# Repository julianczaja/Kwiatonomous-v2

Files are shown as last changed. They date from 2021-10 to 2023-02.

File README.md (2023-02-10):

# Kwiatonomous-v2 

##### Kwiatonomous is a device for automatic plant watering. ESP8266 based, battery powered (super low power), own backend (in Ktor) and Android app (with Jetpack Compose).

___

### Android App
<p align="center">
  
</p>

___

### Hardware
#### v0.5 (306070 Li-Po)
<p align="middle">
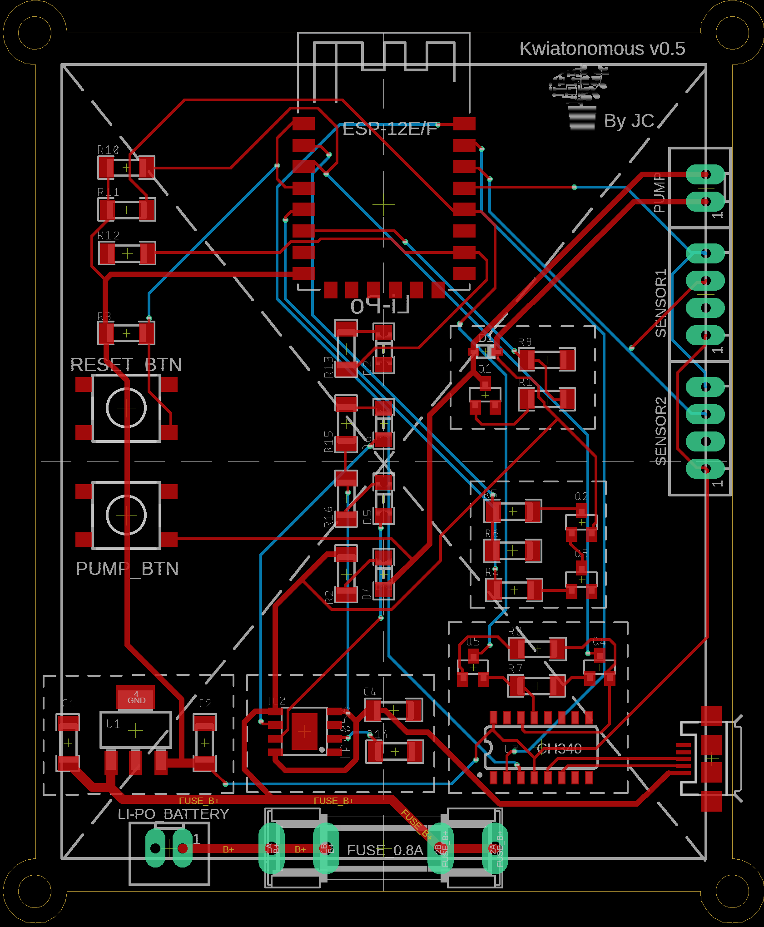
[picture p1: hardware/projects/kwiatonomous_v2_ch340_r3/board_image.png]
  
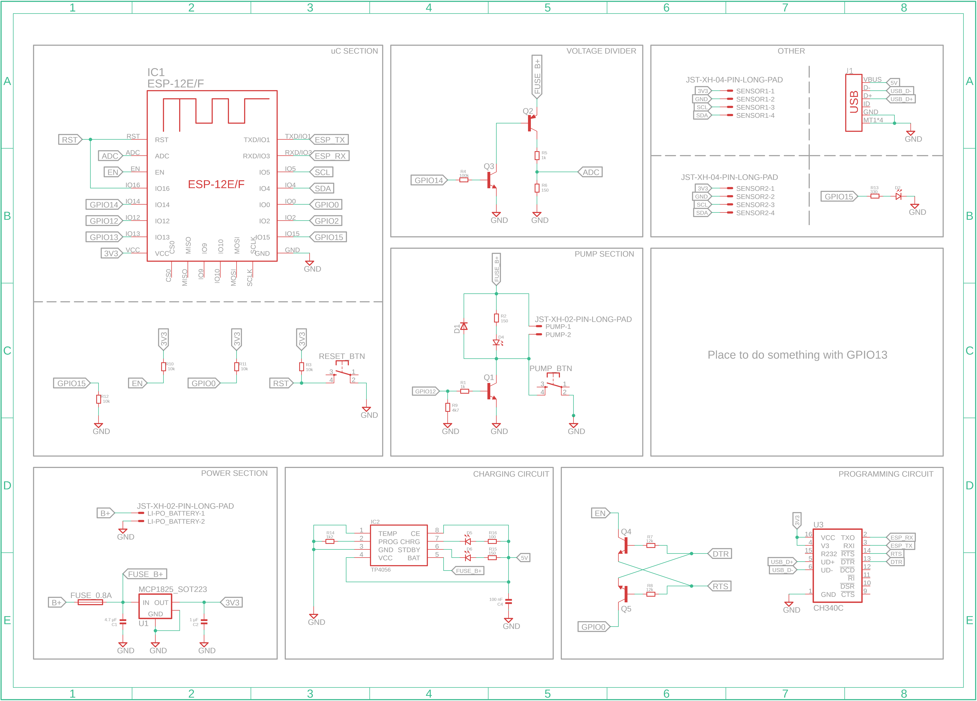
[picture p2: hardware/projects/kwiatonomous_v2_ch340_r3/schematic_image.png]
  
</p>

<details>
  <summary>v0.4 (Li-ion 18650)</summary>
  <p align="middle">
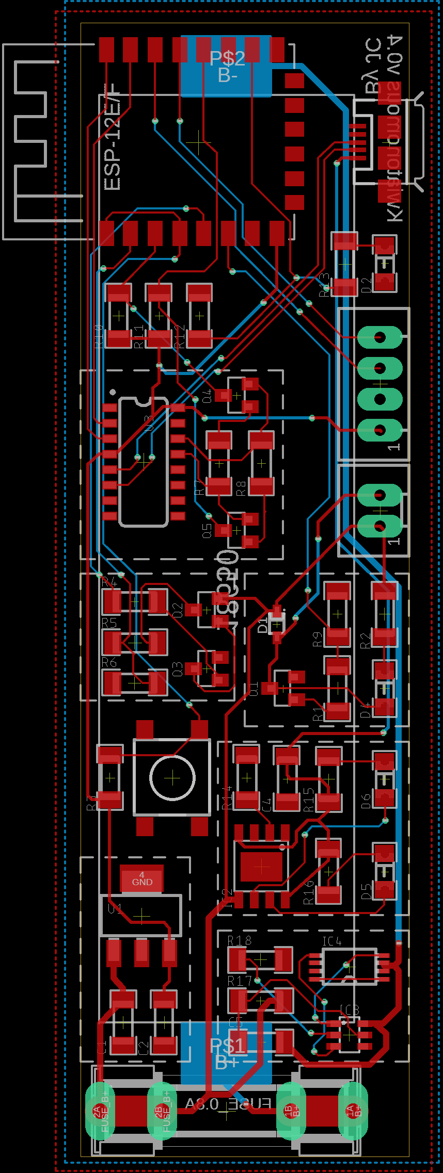
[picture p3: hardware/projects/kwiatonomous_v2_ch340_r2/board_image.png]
    
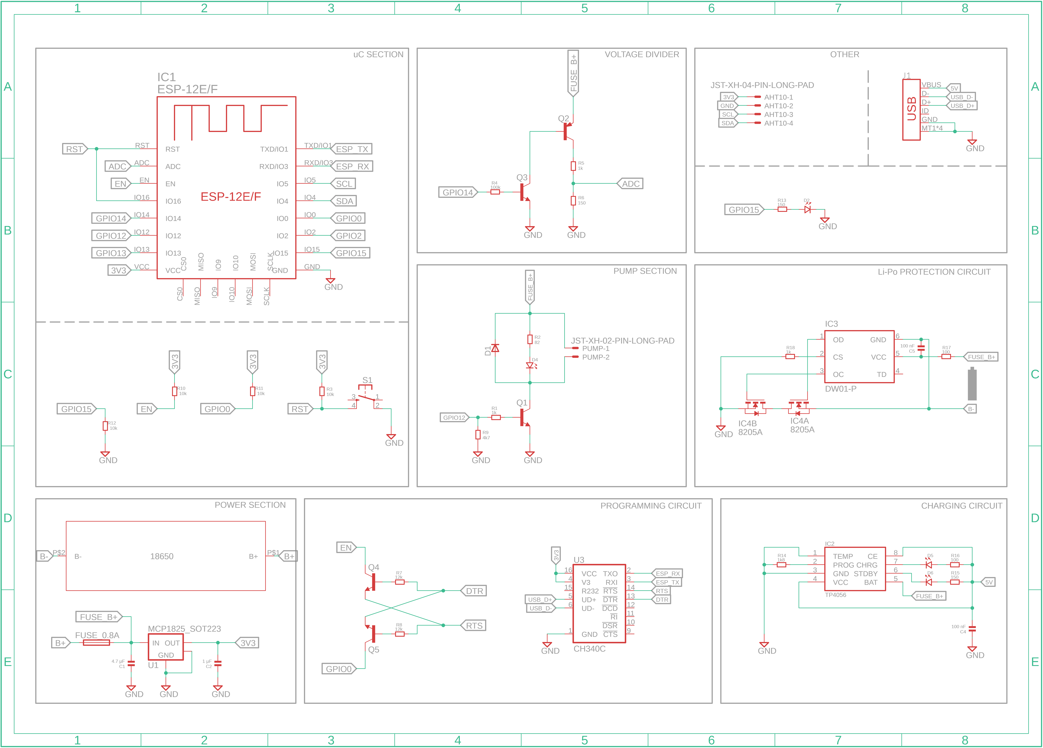
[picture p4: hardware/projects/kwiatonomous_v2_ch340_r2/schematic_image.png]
    
  </p>
</details>

___

### CAD
#### Case for v0.5 PCB

<p align="middle">
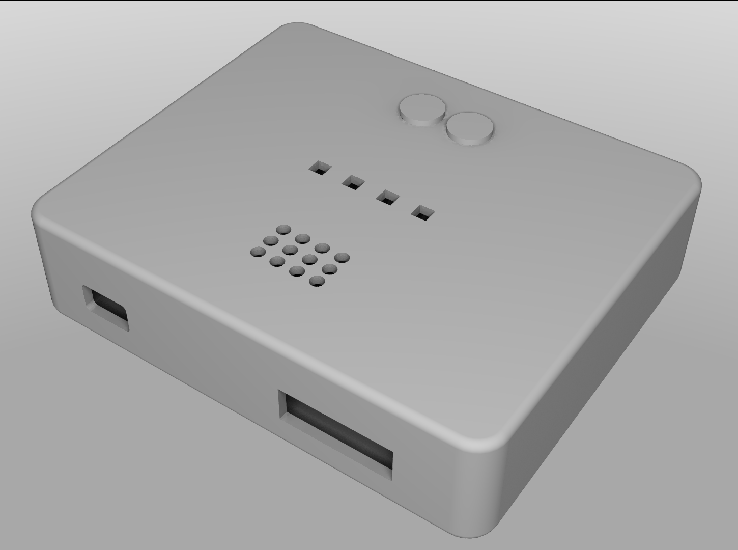
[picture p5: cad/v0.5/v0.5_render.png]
  
</p>
___

<p align="center">
🔥 More comming soon 🔥
</p>

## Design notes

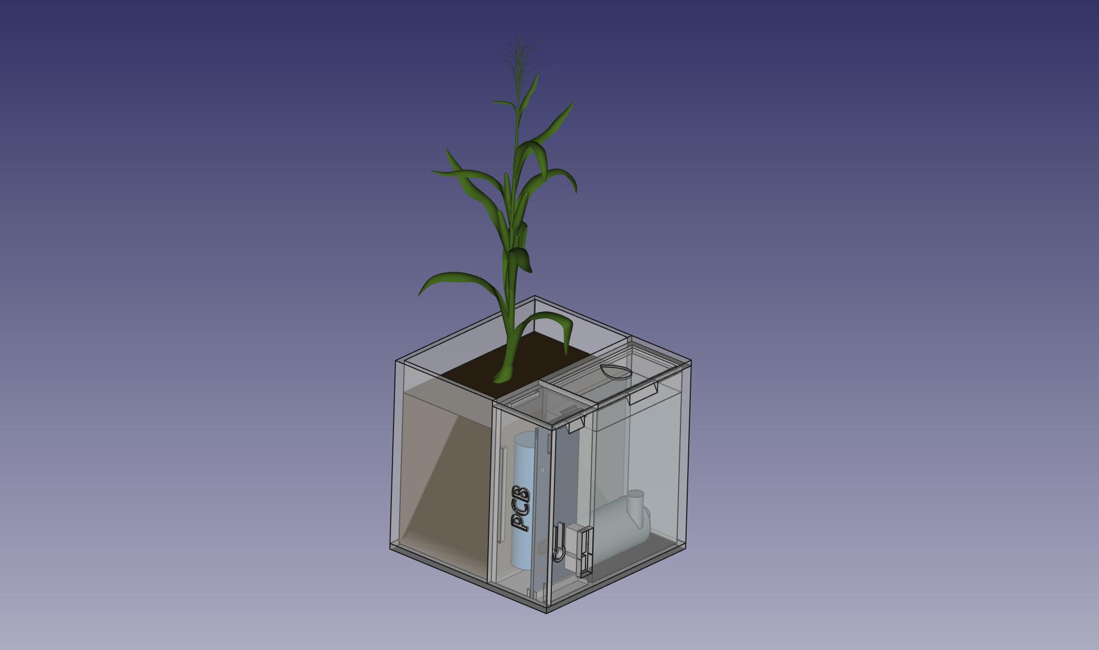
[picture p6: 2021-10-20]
cad/preview.jpeg

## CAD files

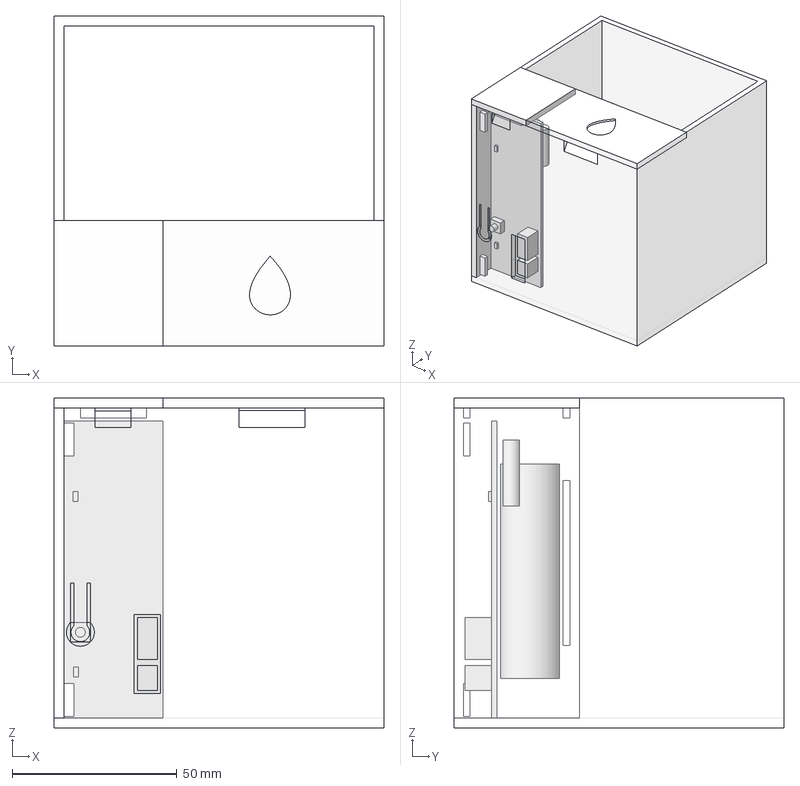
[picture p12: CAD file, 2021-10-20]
cad/kwiatonomous.FCStd
100.0 x 100.0 x 100.0 mm
PCB
pcb top lid
pcb side lid with text
water lid with droplet

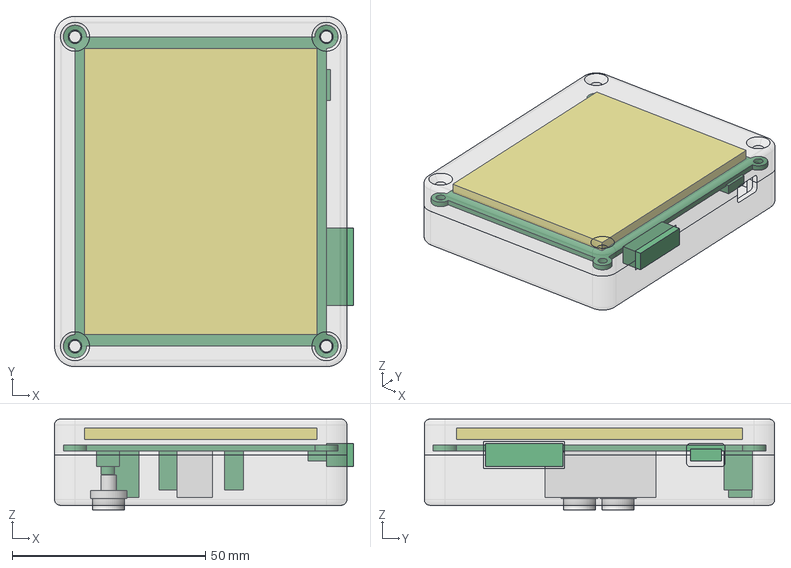
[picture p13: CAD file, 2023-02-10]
cad/v0.5/v0.5_case.FCStd
77.3 x 90.6 x 23.5 mm
PCB
Battery
Case_bottom
Case_top
button
led_parting
button2

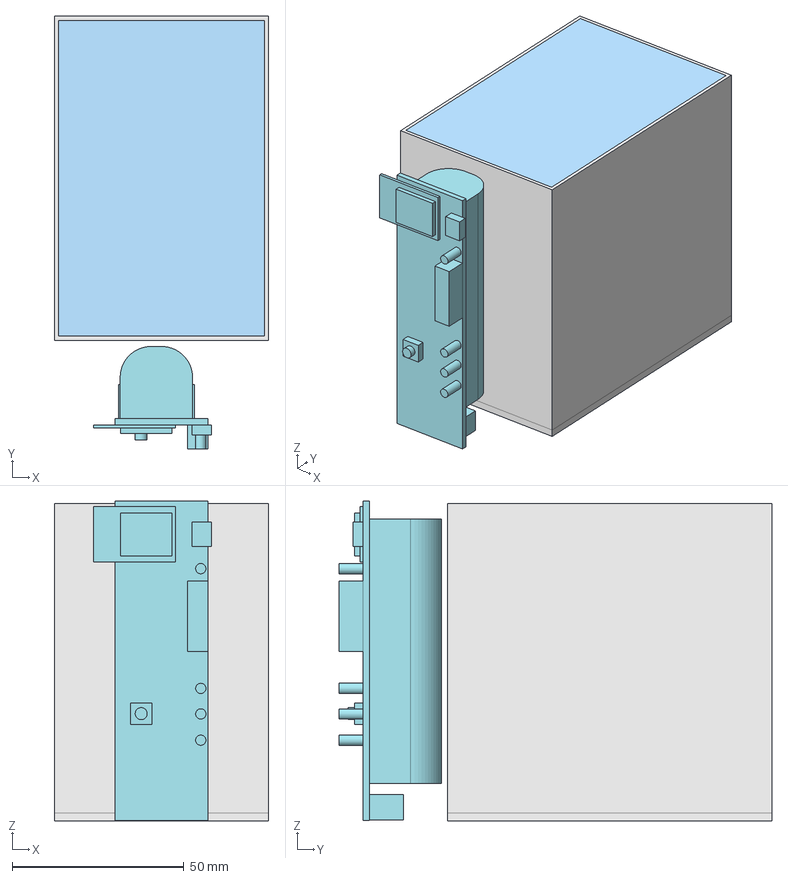
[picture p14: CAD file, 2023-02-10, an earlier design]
cad/v0.4/v0.4_case.FCStd
62.4 x 126.0 x 93.2 mm
pcb
karton
obudowa

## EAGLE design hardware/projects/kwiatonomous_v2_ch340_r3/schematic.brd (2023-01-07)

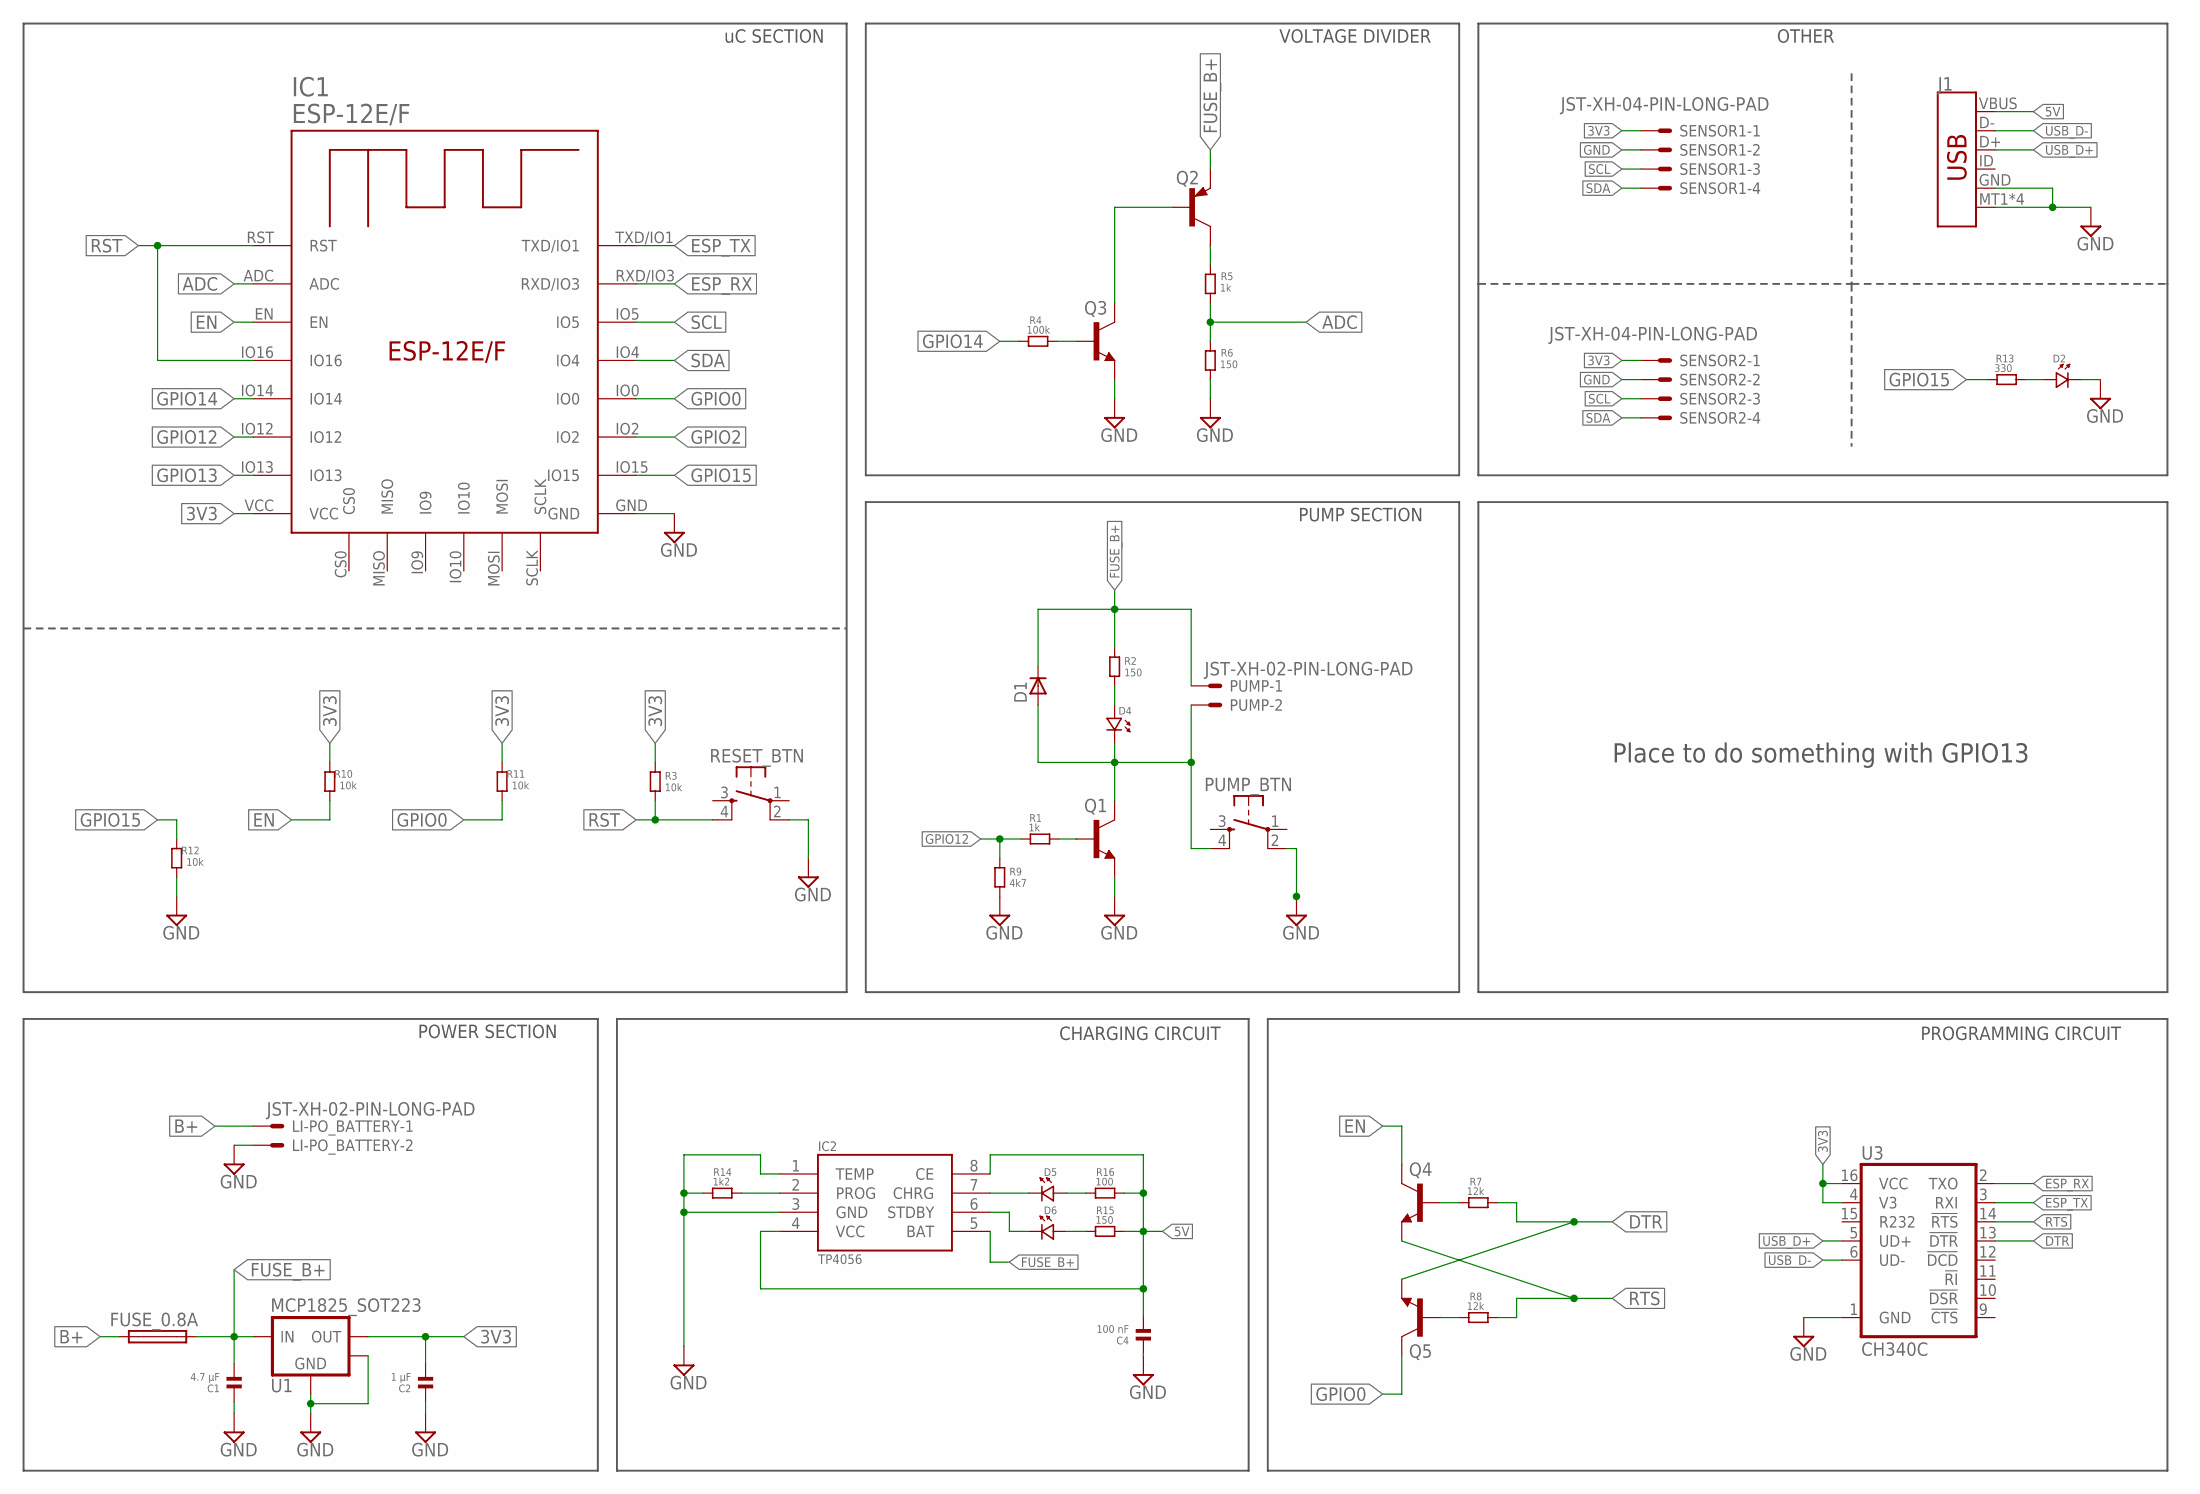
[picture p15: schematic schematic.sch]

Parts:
C1: 4.7 μF; 1206
C2: 1 μF; 1206
C4: 100 nF; 1206
D1: 1N4148WS; SOD323F
D2, D4, D5, D6: LED.1206; 1206.LED
FUSE_0.8A: FUSE_KWIATONOMOUS; SHK20L
IC1: ESP-12E/F; ESP-12E
IC2: TP4056; SOP-8
J1: USB_MICRO-B_SMT; USB-MICROB
LI-PO_BATTERY: JST-XH-02-PIN-LONG-PAD; JST-XH-02-PACKAGE-LONG-PAD
PUMP: JST-XH-02-PIN-LONG-PAD; JST-XH-02-PACKAGE-LONG-PAD
PUMP_BTN: DTSM-6
Q1, Q3, Q4, Q5: BCW71SMD; SOT23-BEC
Q2: BCX71SMD; SOT23
R1, R5: 1k; 1206
R2, R6, R15: 150; 1206
R3, R10, R11, R12: 10k; 1206
R4: 100k; 1206
R7, R8: 12k; 1206
R9: 4k7; 1206
R13: 330; 1206
R14: 1k2; 1206
R16: 100; 1206
RESET_BTN: DTSM-6
SENSOR1, SENSOR2: JST-XH-04-PIN-LONG-PAD; JST-XH-04-PACKAGE-LONG-PAD
U1: MCP1825_SOT223; SOT-223-3
U3: CH340C; SO016

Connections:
3V3: C2.2, IC1.VCC, R3.1, R10.1, R11.1, SENSOR1.1, SENSOR2.1, U1.3 (VOUT), U3.4 (V3), U3.16 (VCC)
5V: C4.2, IC2.4 (VCC), IC2.8 (CE), J1.VBUS, R15.2, R16.2
ADC: IC1.ADC, R5.2, R6.1
B+: FUSE_0.8A.1A (1), FUSE_0.8A.1B (1), LI-PO_BATTERY.1
DTR: Q5.E, R7.2, U3.13 (!DTR)
EN: IC1.EN, Q4.C, R10.2
ESP_RX: IC1.RXD/IO3, U3.2 (TXO)
ESP_TX: IC1.TXD/IO1, U3.3 (RXI)
FUSE_B+: C1.2, D1.C, FUSE_0.8A.2A (2), FUSE_0.8A.2B (2), IC2.5 (BAT), PUMP.1, Q2.2 (E), R2.1, U1.1 (VIN)
GND: C1.1, C2.1, C4.1, D2.P$2 (2), IC1.GND, IC2.1 (TEMP), IC2.3 (GND), J1.GND, J1.MT1 (SHIELD), J1.MT2 (SHIELD), J1.P$1 (SHIELD), J1.P$2 (SHIELD), LI-PO_BATTERY.2, PUMP_BTN.2, Q1.E, Q3.E, R6.2, R9.2, R12.2, R14.1, RESET_BTN.2, SENSOR1.2, SENSOR2.2, U1.2 (GND), U1.4 (HEATSINK), U3.1 (GND)
GPIO0: IC1.IO0, Q5.C, R11.2
GPIO2: IC1.IO2
GPIO12: IC1.IO12, R1.1, R9.1
GPIO13: IC1.IO13
GPIO14: IC1.IO14, R4.1
GPIO15: IC1.IO15, R12.1, R13.1
unnamed: Q1.B, R1.2
unnamed: Q3.B, R4.2
unnamed: D4.P$1 (1), R2.2
unnamed: D1.A, D4.P$2 (2), PUMP.2, PUMP_BTN.4, Q1.C
unnamed: Q2.3 (C), R5.1
unnamed: Q5.B, R8.1
unnamed: Q4.B, R7.1
unnamed: D2.P$1 (1), R13.2
unnamed: IC2.2 (PROG), R14.2
unnamed: D5.P$2 (2), IC2.7 (CHRG)
unnamed: D6.P$1 (1), R15.1
unnamed: D5.P$1 (1), R16.1
unnamed: D6.P$2 (2), IC2.6 (STDBY)
PG: Q2.1 (B), Q3.C
RST: IC1.IO16, IC1.RST, R3.2, RESET_BTN.4
RTS: Q4.E, R8.2, U3.14 (!RTS)
SCL: IC1.IO5, SENSOR1.3, SENSOR2.3
SDA: IC1.IO4, SENSOR1.4, SENSOR2.4
USB_D+: J1.D+, U3.5 (UD+)
USB_D-: J1.D-, U3.6 (UD-)

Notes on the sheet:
POWER SECTION
PROGRAMMING CIRCUIT
OTHER
uC SECTION
PUMP SECTION
VOLTAGE DIVIDER
CHARGING CIRCUIT
Place to do something with GPIO13

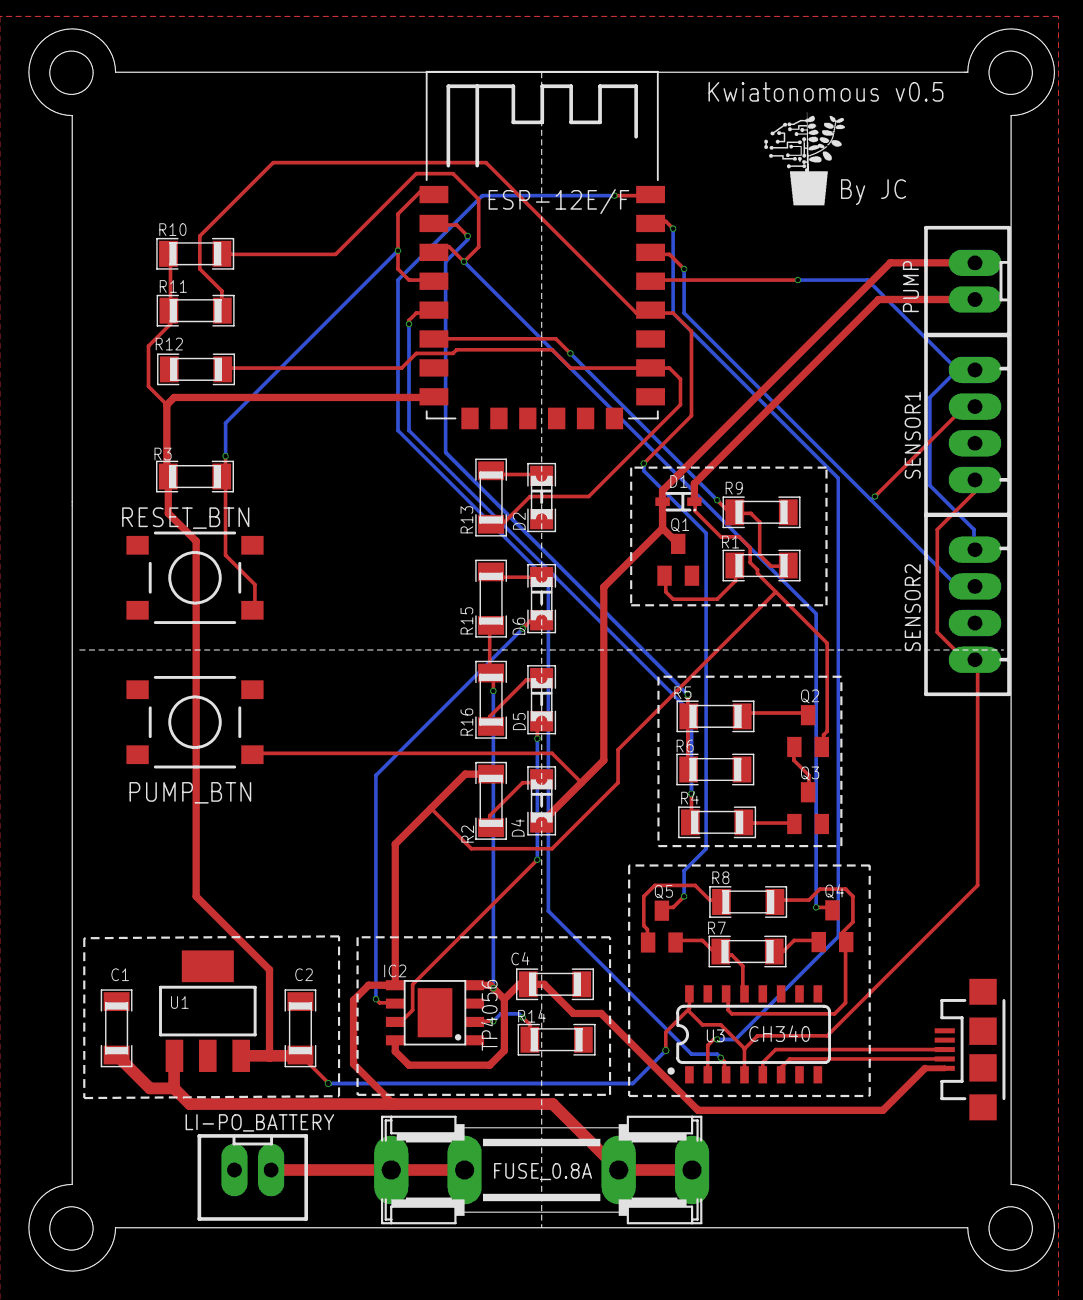
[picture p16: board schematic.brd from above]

Board: 2 copper layers, 71.0 x 86.0 mm, 41 parts (0 on the bottom side), 34 nets.

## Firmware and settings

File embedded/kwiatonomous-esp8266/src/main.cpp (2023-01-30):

#include <Arduino.h>
#include <ESP8266WiFi.h>
#include <WiFiUdp.h>
#include <NTPClient.h>
#include <Adafruit_AHTX0.h>

#include "Led.h"
#include "BatteryManager.h"
#include "WateringManager.h"
#include "DataManager.h"
#include "DeviceConfiguration.h"
#include "WiFiConfiguration.h"
#include "DeviceUpdate.h"
#include "KwiatonomousApi.h"

#define LED_BLUE_PIN 15
#define LED_BUILTIN_PIN 2
#define VOLTAGE_DIVIDER_PIN 14
#define PUMP_PIN 12
#define BATTERY_VOLTAGE_PIN A0

#define BATTERY_LOW_THRESHOLD_VOLTAGE 3.3 // V
#define SLEEP_TIME_DEFAULT 30 * 60e6      // us
#define WIFI_CONNECTION_TIMEOUT 15e3      // ms
#define NTP_TIMEOUT 5e3                   // ms

#define DEVICE_ID "testid"

void lowBatteryCallback();
void onError(char *message);
void goToSleep(unsigned long sleepTime);
void connectToWifi(WiFiConfiguration *wifiConfiguration);
unsigned long getEpochTime(int16_t timeZoneOffset);

Led ledBuiltin = Led(LED_BUILTIN_PIN);
Led ledInfo = Led(LED_BLUE_PIN);
WateringManager wateringManager = WateringManager(PUMP_PIN);
DataManager dataManager = DataManager();
KwiatonomousApi kwiatonomousApi = KwiatonomousApi();
BatteryManager batteryManager = BatteryManager(BATTERY_VOLTAGE_PIN,
                                               VOLTAGE_DIVIDER_PIN,
                                               25,
                                               20,
                                               &lowBatteryCallback);

void setup()
{
  Serial.begin(115200);
  Serial.println("\nHello world!\n\n");

  ledBuiltin.init(false);
  ledBuiltin.on(1);
  ledInfo.init(false);
  ledInfo.on(5);
  batteryManager.init();
  wateringManager.init();
  dataManager.init();
  delay(250);

  Serial.print("Failure count: ");
  Serial.println(dataManager.getFailuresCount());

  // Get battery status before Wi-Fi is on
  // If battery too low just go to sleep for max time (soft safeguard)
  batteryManager.update();
  float currentVoltage = batteryManager.getBatteryVoltage();
  Serial.print("Current voltage: ");
  Serial.println(currentVoltage);
  Serial.print("Current battery level: ");
  Serial.println(batteryManager.getBatteryLevel());
  if (currentVoltage <= BATTERY_LOW_THRESHOLD_VOLTAGE)
  {
    ledInfo.signalizeLowBattery();
    goToSleep(ESP.deepSleepMax());
    return;
  }

  // Get temperature and humidity from AHT sensor
  Adafruit_AHTX0 aht;
  sensors_event_t sensor_temperature, sensor_humidity;
  if (aht.begin())
  {
    aht.getEvent(&sensor_humidity, &sensor_temperature);
  }
  else
  {
    onError((char *)"Couldn't find AHT. Check wiring!");
  }

  // Connect to Wi-Fi
  WiFiConfiguration wifiConfiguration = WiFiConfiguration();
  dataManager.getWiFiConfiguration(&wifiConfiguration);
  connectToWifi(&wifiConfiguration);

  kwiatonomousApi.init((char *)DEVICE_ID);

  // Get device configuration
  DeviceConfiguration configuration = DeviceConfiguration();
  bool getDeviceConfigurationSuccess = kwiatonomousApi.getDeviceConfiguration(&configuration);
  if (getDeviceConfigurationSuccess == false)
  {
    onError((char *)"Can't get device configuration");
  }

  // Save device configuration to EEPROM
  dataManager.setDeviceConfiguration(&configuration);

  // Get next watering info
  bool getNextWateringSuccess = kwiatonomousApi.getNextWatering(&(wateringManager.nextWatering));
  if (getNextWateringSuccess == false)
  {
    onError((char *)"Can't get next watering");
  }

  DeviceUpdate deviceUpdate = DeviceUpdate();
  deviceUpdate.epochTime = getEpochTime(configuration.timeZoneOffset * 3600);
  deviceUpdate.batteryLevel = batteryManager.getBatteryLevel();
  deviceUpdate.batteryVoltage = batteryManager.getBatteryVoltage();
  deviceUpdate.temperature = sensor_temperature.temperature;
  deviceUpdate.humidity = sensor_humidity.relative_humidity;

  // Update watering manager
  wateringManager.update(configuration, deviceUpdate.epochTime);
  if (wateringManager.nextWateringUpdated == true)
  {
    if (kwiatonomousApi.updateNextWatering(wateringManager.nextWatering) == false)
    {
      //                  TODO
      // Important part - update next watering time
      // If the time won't be updated, that plant will
      // be watered on each wake up
      //
      // Maybe save info about failure to EEPROM?
    }
    else
    {
      kwiatonomousApi.sendWateringEvent(deviceUpdate.epochTime);
    }
  }

  // Send device update
  if (kwiatonomousApi.sendUpdate(&deviceUpdate) == false)
  {
    onError((char *)"Can't send device update");
  }

  // Finish http connection
  delay(200);
  kwiatonomousApi.end();
  delay(100);

  // Everything done, go to sleep
  unsigned long sleepTimeMicros = configuration.sleepTimeMinutes * 60e6;
  goToSleep(sleepTimeMicros);
}

void loop() {}

void connectToWifi(WiFiConfiguration *wifiConfiguration)
{
  Serial.println("Connecting to Wi-Fi...");

  unsigned long *startConnection = (unsigned long *)malloc(sizeof(unsigned long));
  *startConnection = millis();

  WiFi.begin(wifiConfiguration->ssid, wifiConfiguration->password);
  WiFi.setOutputPower(20.5f);
  WiFi.setPhyMode(WIFI_PHY_MODE_11B);

  while (WiFi.status() != WL_CONNECTED)
  {
    if ((millis() - *startConnection) > WIFI_CONNECTION_TIMEOUT)
    {
      onError((char *)"Can't connect to Wi-Fi");
    }
    Serial.print(".");
    ledInfo.dim(1000);
  }
  free(startConnection);

  Serial.print("\nConnected with IP: ");
  Serial.println(WiFi.localIP());

  ledInfo.on(5);
}

unsigned long getEpochTime(int16_t timeZoneOffset)
{
  Serial.println("\n> getEpochTime");

  WiFiUDP ntpUDP;
  NTPClient timeClient(ntpUDP, "pool.ntp.org");

  timeClient.begin();
  timeClient.setTimeOffset(timeZoneOffset);

  unsigned long startNtp = millis();
  bool ntpSuccess = false;
  unsigned long epochTime = 0;

  while ((ntpSuccess = timeClient.update()) != true)
  {
    if ((millis() - startNtp) > NTP_TIMEOUT)
    {
      break;
    }
    delay(100);
  }

  if (ntpSuccess)
  {
    epochTime = timeClient.getEpochTime();
    Serial.print("Current epoch time: ");
    Serial.println(epochTime);

    // https://github.com/gmag11/NtpClient/issues/70
    // If error in UDP packet (year bigger than 2035) - sleep
    if (epochTime > 2051222400)
    {
      onError((char *)"Something is wrong with epochTime (year > 2035)");
    }
  }
  else
  {
    onError((char *)"Can't get epochTime");
  }

  timeClient.end();

  return epochTime;
}

void lowBatteryCallback()
{
  Serial.println("LOW BATTERY!!!");
  ledInfo.signalizeLowBattery();
}

void onError(char *message)
{
  Serial.print("Error! Message: ");
  Serial.println(message);
  dataManager.increaseFailuresCount();
  ledInfo.signalizeLowBattery();
  kwiatonomousApi.end();

  DeviceConfiguration savedDeviceConfiguration = DeviceConfiguration();
  dataManager.getDeviceConfiguration(&savedDeviceConfiguration);

  if (savedDeviceConfiguration.sleepTimeMinutes == 0)
  {
    goToSleep(SLEEP_TIME_DEFAULT);
  }
  else
  {
    // Sleep for half of normal time
    unsigned long sleepTimeMicros = (savedDeviceConfiguration.sleepTimeMinutes * 60e6) / 2;
    goToSleep(sleepTimeMicros);
  }
}

void goToSleep(unsigned long sleepTimeMicros)
{
  Serial.print("\nGoing to sleep for ");
  Serial.print(sleepTimeMicros / 60e6);
  Serial.println(" minutes!");
  Serial.flush();
  Serial.end();
  ledInfo.off();
  ledBuiltin.off();

  ESP.deepSleepInstant(sleepTimeMicros - micros(), RF_NO_CAL);
}

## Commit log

2021-10-20 Added Eagle files
    [schematic.brd, schematic.sch]
2021-10-20 Added cad files
    [kwiatonomous.FCStd]
2021-10-30 backend/Refactored DeviceUpdate class
2021-10-30 android/Implemented DeviceUpdate API calls
2021-11-07 android/Added navigation and device updates. UI improvements.
2021-11-15 embedded/Improved battery manager. Code cleanup.
2021-11-15 embedded/Improved sleeping intervals and errors handling
    [main.cpp]
2021-11-28 backend/Added nextWatering to DeviceUpdate class
2021-11-28 backend/Implemented device configuration table and improved next watering
2021-11-30 embedded/Implemented device configuration and watering
2021-11-30 android/Added nextWatering to Device. Improved DeviceItem composable.
2021-11-30 android/Added device configuration.
2021-12-05 backend/Removed nextWatering from DeviceUpdate. Added wateringTime to DeviceConfiguration
2021-12-12 android/Added device settings
2021-12-18 backend/Added picking device updates from/to timestamp
2021-12-28 android/Added unit tests for Device usecases
2021-12-28 android/Added unit tests for DeviceConfiguration usecases
2021-12-28 android/Added unit tests for DeviceUpdate usecases
2021-12-29 android/Moved DashboardScreen stuff to DeviceDetailsScreen. Implemented basic menu in dashboard.
2022-01-07 backend/Switched from Netty to Jetty engine. Gradle dependencies update.
2022-01-07 embedded/Fixed watering manager bug with device start after long shutdown
2022-01-09 backend/Added timeZoneOffset to Device table
2022-01-09 android/Implemented device time zone offset
2022-01-10 android/Added 'Reset changes' button to device configuration screen. Improved error handling
2022-01-10 android/Added device active state indicator
2022-01-10 android/Improved 'update' usecases to emit flow
2022-01-13 android/Fixed device configuration conversion
2022-01-25 android/Fixed problem with automatic dark mode on Xiaomi devices
2022-01-30 android/Implemented DevicesViewModel unit tests
2022-01-30 android/Implemented DeviceDetailsViewModel unit tests
2022-01-30 android/Refactored DeviceItem to work better with polish language
2022-02-01 android/Set 'day' as default chart type in device details screen. Fixed string typo
2022-02-03 android/Refactored DevicesScreen to show UserDevices
2022-02-08 android/Refactored DAOs
    - Implemented 'addOrUpdate' function in DeviceDao, DeviceUpdateDao, DeviceConfigurationDao
    - Refactored use cases to use addOrUpdate
    - Changed naming
2022-02-10 backend/Fixed get device updates route to return empty list instead of 404
2022-02-14 android/Refactored device details screen
    - Added UserDevice section
    - Moved DeviceItem and changet its UI
2022-02-16 android/Implemented editing current UserDevice
2022-02-16 android/Removed unnecessary job from DevicesViewModel
2022-02-19 android/Added confirmation dialog when deleting user device
2022-03-14 hardware/Added new board revision files
    [schematic.brd, schematic.sch]
2022-05-10 android/Added last update info to device view
2022-05-15 android/Improved getting last devices updates
2022-05-17 android/Added battery level to device item
2022-05-27 backend/Switched kotlinx-json to gson
2022-05-27 backend/Implemented digest authentication
    - Added User table
    - Refactored all routes
    - Created separate routes for ESP devices
2022-06-27 android/Implemented device updates table view
2022-06-27 android/Fixed bug that caused device updates duplication
2022-06-28 android/Disabled device updates table button when list is empty
2022-07-05 android/Added notification on/off setting to UserDevice
    - Extracted content of AddEditUserDeviceScreen for preview
    - Added notifications toggle in AddEditUserDeviceScreenContent
    - Added notifications toggle icon in DeviceDetailsScreen
    - Moved AppSettingsToggleItem to common components
2022-07-27 android/Adjusted font in DeviceItem and DeviceConfigurationItem
2022-08-08 android/Implemented events
    - Added event models (DeviceEvent + entity and dto)
    - Added event enpoints to KwiatonomousApi
    - Added new database entity
    - Added device event repository
    - Added basic composable to display events
2022-08-12 android/Implemented adding device events
    - ExpandableFloatingActionButton is used to choose what event user wants to add
    - Added AddDeviceEventUseCase
    - Added simple dialogs for UserNote and Watering events
    - Events UI improvements - new icons
    - minor fixes with scaffold's padding (because of compose 1.2.0)
2022-08-22 android/Implemented adding device low battery events
2022-08-22 backend/Changed UserDevice's deviceImageId to deviceImageName
2022-08-23 android/Refactored getDeviceEvents to get all user's devices' events
2022-08-24 android/Added button to remove devices cache
    - refactored app settings screen for better preview
    - implemented ClearDevicesCacheUseCase
    - added removeAll() function to all repositories
    -
2022-08-25 android/Implemented hiding fab on scroll in DeviceDetailsScreen
2022-08-26 android/Implemented removing device events
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2022-11-15 backend/Added pump cleaning, updated dependencies, bumped version
2022-11-15 android/Added pump cleaning event and reminder
    - added KwiatonomousBroadcastReceiver
    - added lastPumpCleaning to Device
    - added notifications testing buttons in settings
    - added PumpCleaningWorker
    - added pump cleaning event
    - refactored BatteryBatteryInfoWorker
    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
2022-11-17 android/Code cleanup in DeviceSettings VM and screen
2022-11-21 android/Devices and device details screens refactor. Dependencies bump
    - replaced accompanist swipe-refresh with compose one
    - added caching to GetUserDevicesWithLastUpdatesUseCase
    - switched from State to StateFlow in view models
2022-11-21 android/Fixed bug in DeviceUpdateRepositoryImpl
    - limit param was not passed to DAO function
2022-11-21 android/Fixed bug with not updated uiState when user don't have devices added
2022-11-21 android/Fixed bug with not updated state when user added a device
2022-11-22 android/Removed unused "lastUpdated" fields from Device and DeviceConfiguration tables
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2022-11-24 android/Improved dashboard screen
    - uiStateStream has now single source of truth (db)
    - fixed bug with flow being emitted too many times
    - code cleanup
2022-12-15 embedded/Added soft low battery protection. Adjusted battery level formula. Added low battery event code
2023-01-07 hardware/Added v0.5 version of PCB
    - replaced 18650 with Li-Po
    - added button for manual pump powering
    - new design
    [schematic.brd, schematic.sch]
2023-01-30 embedded/Minor changes
    - updated AHT library to 2.0.3
    - adjusted LEDs sequences
    - adjusted WiFi settings to extend range
    - Code cleanup
2023-02-10 android/Fixed preloading old data on devices screen
2023-02-10 cad/Added case files for v0.5 PCB
    [kwiatonomous.FCStd, v0.4_case.FCStd, v0.5_case.FCStd]
2023-03-29 android/bumped dependencies, fixed crash during filtering new updates
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

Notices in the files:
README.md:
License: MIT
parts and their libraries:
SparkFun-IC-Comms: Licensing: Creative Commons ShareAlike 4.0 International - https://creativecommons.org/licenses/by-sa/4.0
